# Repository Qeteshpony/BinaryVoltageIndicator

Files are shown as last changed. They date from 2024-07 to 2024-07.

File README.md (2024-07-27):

# Binary Voltage Indicator



3D Render

[Hardware Documentation](https://qeteshpony.github.io/BinaryVoltageIndicator)

A small board that can be attached to a 5V power supply to show if the voltage is above or below 5.0V with a maximum tolerance of about 2% (±0.1V) when 1% resistors are used.

The board can also be directly plugged onto a Raspberry Pi GPIO header to have a quick visual aid about the power supply status. The third pin is an open collector output that pulls down when the voltage is above 5.0V. When plugged onto the GPIO header this gets connected to GPIO14. 

Connections when directly plugged in:

| Board | GPIO Header|
|:---|:---|
|  VCC  | 4 (5V) |
|  GND  | 6 (GND) |
|  VOK  | 8 (GPIO14) |

When using a cable, VOK can of course be connected to any GPIO Pin or not be used at all. 

The "wings" with the screw holes can be used to mount the board in a case or broken off if they are not needed.

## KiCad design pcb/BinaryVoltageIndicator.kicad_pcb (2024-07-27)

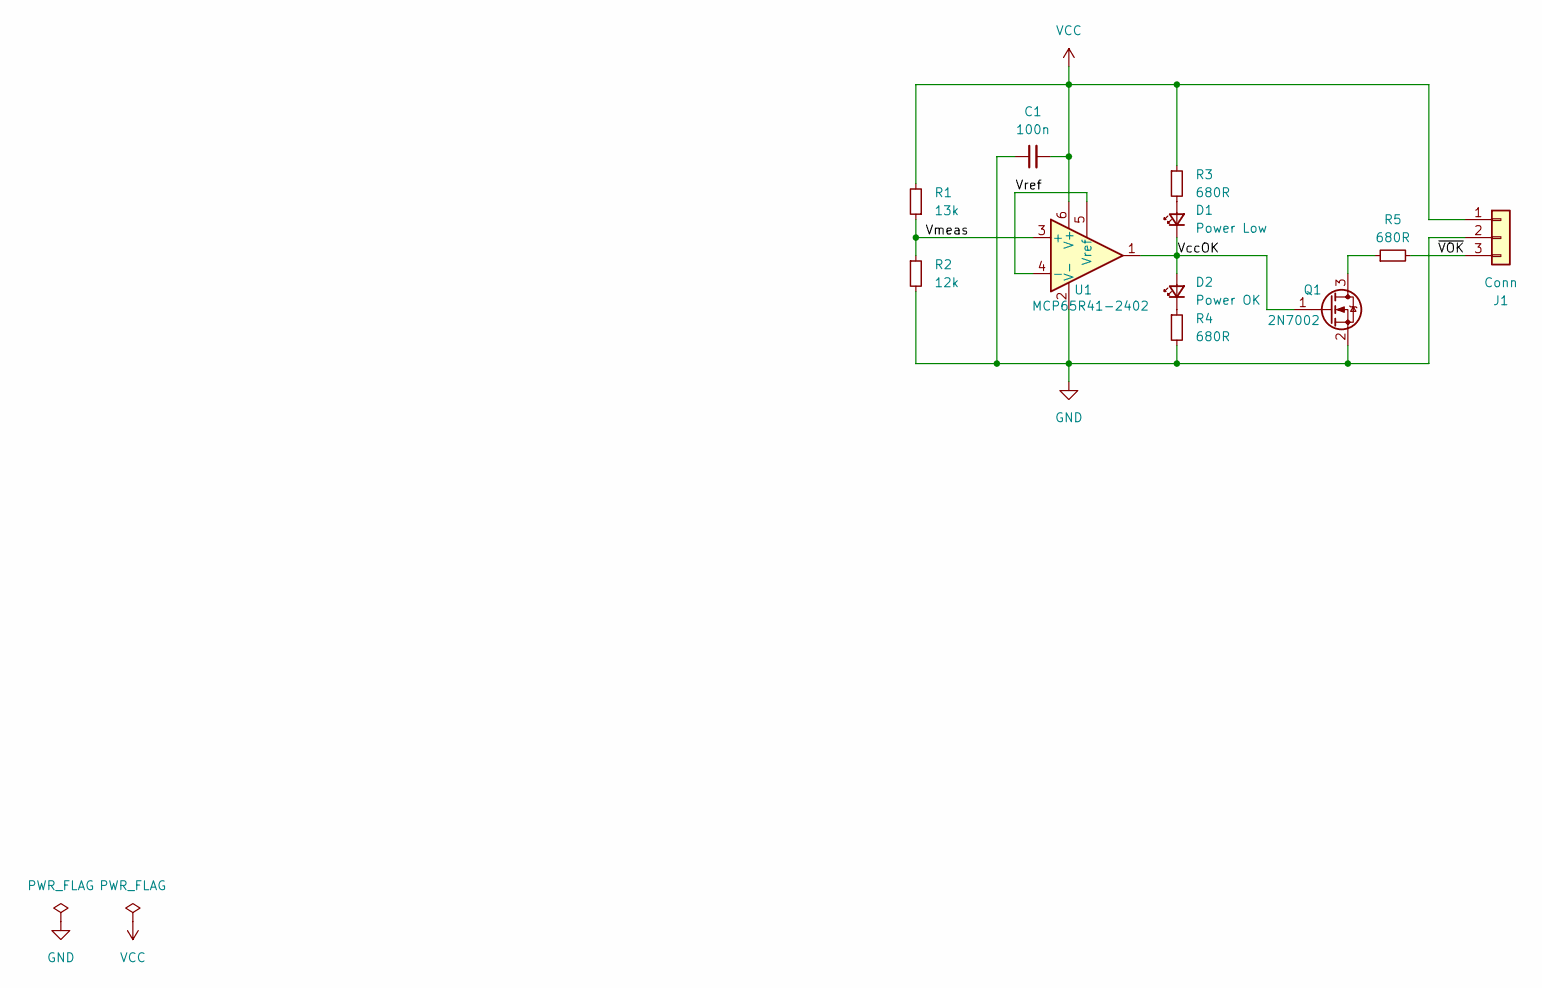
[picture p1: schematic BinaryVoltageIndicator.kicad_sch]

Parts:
C1: 100n; C_0402_1005Metric; LCSC C1525
D1: Power Low; LED_0603_1608Metric; LCSC C2286
D2: Power OK; LED_0603_1608Metric; LCSC C2986059
J1: Conn; PinHeader_1x03_P2.54mm_Vertical
Q1: 2N7002; SOT-23; LCSC C8545
R1: 13k; R_0603_1608Metric; LCSC C22797
R2: 12k; R_0603_1608Metric; LCSC C22790
R3, R4, R5: 680R; R_0402_1005Metric; LCSC C25130
U1: MCP65R41-2402; SOT-23-6; LCSC C145386

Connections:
/VccOK: D1.1 (K), D2.2 (A), Q1.1 (G), U1.1
/Vmeas: R1.1, R2.1, U1.3 (+)
/Vref: U1.4 (-), U1.5 (Vref)
/~VOK: J1.3, R5.2
GND: C1.1, J1.2, Q1.2 (S), R2.2, R4.2, U1.2 (V-)
unnamed: D1.2 (A), R3.2
unnamed: D2.1 (K), R4.1
unnamed: Q1.3 (D), R5.1
VCC: C1.2, J1.1, R1.2, R3.1, U1.6 (V+)

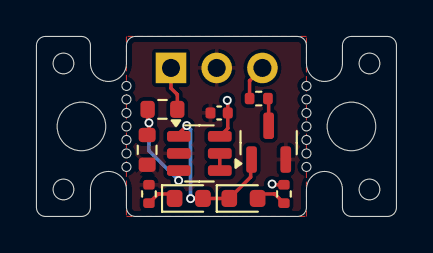
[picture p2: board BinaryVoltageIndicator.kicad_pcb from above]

Board: 2 copper layers, 20.0 x 10.0 mm, 13 parts (1 on the bottom side), 9 nets.

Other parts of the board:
mouse-bite-2mm-slot, mouse-bite-2mm-slot#2: VAL**; mouse-bite-2x5mm-slot-onesided-v2

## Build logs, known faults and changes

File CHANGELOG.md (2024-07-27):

# Changelog

## [1.0.1](https://github.com/Qeteshpony/BinaryVoltageIndicator/compare/v1.0.0...v1.0.1) (2024-07-27)

### Bug Fixes

* change measurement resistors to 0603 ([05b6b9b](https://github.com/Qeteshpony/BinaryVoltageIndicator/commit/05b6b9b6478d0bfc628f92969f97318b8e912318))

## 1.0.0 (2024-07-27)

### Features

* initial release ([a7076a2](https://github.com/Qeteshpony/BinaryVoltageIndicator/commit/a7076a26aa426776c41e3344da3115dd33cd4bca))

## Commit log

2024-07-27 feat: initial release
    [BinaryVoltageIndicator.kicad_pcb, BinaryVoltageIndicator.kicad_sch]
2024-07-27 fix: change measurement resistors to 0603
    the 0402 resistors in JLCPCBs standard library are 5% - too much for this to work properly
    [BinaryVoltageIndicator.kicad_pcb, BinaryVoltageIndicator.kicad_sch]
